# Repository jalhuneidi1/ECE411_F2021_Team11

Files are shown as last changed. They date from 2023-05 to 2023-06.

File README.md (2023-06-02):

# ECE411 Sunrise Alarm Clock - Team 7
> "Never wake-up in darkness..."

Project created for ECE 411 - Industry Design Processes

Team Members - Jana, Maddie, Ashlei, Julia

*__Note: The final product of this project utilized a completely different set of hardware. Updates forthcoming. The Sunrise Alarm Clock is an add on board for an arduino which allows users to interact with an OLED display clock using guestures (videos demonstration of final product can be found in the [Demo directory](https://github.com/jalhuneidi1/ECE411_F2021_Team7/tree/main/Demo). The board features 12 RGB SMD LEDs which are used to display time in a meaningful way, indicate confirmation of guesture input, and provide an illuminated alarm experience. A buzzer along with two analog buttons are included to facilitate traditional inputs and alarms if necessary.__*

View the [Product Design Specification](./Product%20Design%20Specification%20v1.pdf) for more information.

Look at the [Project Board](https://github.com/31415pi/ECE_411_Winter_2021_Team_7/projects/1).

Schematic located at [Hardware/Schematic](./Hardware/Schematic.pdf).

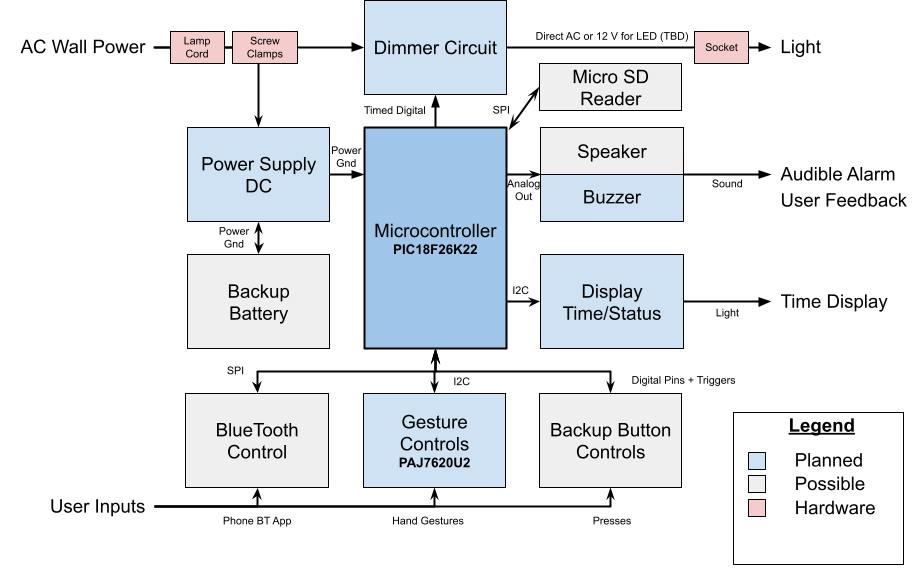
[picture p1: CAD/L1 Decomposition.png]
L1 Decomposition


## Parts List

Parts list on [google drive](https://docs.google.com/spreadsheets/d/1yFu2dnekZCLbKxV9tUKsMTaaS4XpjHtpUTBXEi358RU/edit#gid=0). [Convert to Markdown](https://tabletomarkdown.com/convert-spreadsheet-to-markdown/).

| Part (datasheet link) | Name | Type | Notes | Datasheet | Website | Source | Price  |
| --- | --- | --- | --- | --- | --- | --- | --- |
| [HT16K33](https://github.com/31415pi/ECE_411_Winter_2021_Team_7/blob/main/Datasheets/HT16K33v120(LEDcontroller).pdf) | RAM Mapping 16\*8 LED Controller Driver with keyscan | LED Controller  | | | [https://www.holtek.com/productdetail/-/vg/16K33](https://www.holtek.com/productdetail/-/vg/16K33) | | |
| [PIC18F26K42](https://github.com/31415pi/ECE_411_Winter_2021_Team_7/blob/main/Datasheets/PIC18(L)F26-27-45-46-47-55-56-57K42-Data-Sheet-40001919G.pdf) | | Microcontroller | Actual Model Read from Chip. | [https://www.microchip.com/content/dam/mchp/documents/MCU08/ProductDocuments/DataSheets/PIC18(L)F26-27-45-46-47-55-56-57K42-Data-Sheet-40001919G.pdf](https://www.microchip.com/content/dam/mchp/documents/MCU08/ProductDocuments/DataSheets/PIC18(L)F26-27-45-46-47-55-56-57K42-Data-Sheet-40001919G.pdf) | [https://www.microchip.com/en-us/product/PIC18F26K42](https://www.microchip.com/en-us/product/PIC18F26K42) | EPL | $ 1.50 |
| [IRM-05-5](https://github.com/31415pi/ECE_411_Winter_2021_Team_7/blob/main/Datasheets/IRM-05(ac-5vsupply).pdf) | | DC Power Supply | | | | [Mouser](https://www.mouser.com/ProductDetail/709-IRM05-5) | $ 8.81 |
| [MOC3052TVM](https://github.com/31415pi/ECE_411_Winter_2021_Team_7/blob/main/Datasheets/MOC3052M(ACcont).pdf) | | AC Controller | | | | [Mouser](https://www.mouser.com/ProductDetail/512-MOC3052SR2M)  | $ 1.15 |
| [ACST410-8BTR](https://github.com/31415pi/ECE_411_Winter_2021_Team_7/blob/main/Datasheets/ACST410(ACswitch).pdf) | | AC Switch | | | | [Mouser](https://www.mouser.com/ProductDetail/511-ACST410-8BTR) | $ 0.85 |
| [SFH628A](https://github.com/31415pi/ECE_411_Winter_2021_Team_7/blob/main/Datasheets/SFH628A(ACsensor).pdf) | | AC Sensor | | | | [Mouser](https://www.mouser.com/ProductDetail/782-SFH6286-4T) | $ 1.27 |
| [COM-10931](https://github.com/31415pi/ECE_411_Winter_2021_Team_7/blob/main/Datasheets/COM-10931_ATA3492BW(7seg4digitSparkfun).pdf) | 7-Segment Display - 4-Digit (White) | Time Display | | [http://cdn.sparkfun.com/datasheets/Components/LED/ATA3492BW\_2.pdf](http://cdn.sparkfun.com/datasheets/Components/LED/ATA3492BW_2.pdf) | [https://www.sparkfun.com/products/10931](https://www.sparkfun.com/products/10931) | [Mouser](https://www.mouser.com/ProductDetail/474-COM-10931) | $ 2.63 |

Alternate [Sparkfun Time Display](https://www.sparkfun.com/products/10931).

## Tools

- KiCad. [Third Party Libraries](https://www.kicad.org/libraries/third_party/)
- [Library Loader](https://componentsearchengine.com/tools) for loading schematics into KiCad and others. [Setup Instructions](https://www.samacsys.com/kicad/)

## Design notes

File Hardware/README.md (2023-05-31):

# Hardware Notes

Add libraries to KiCad. <https://www.samacsys.com/kicad/>

## Revisions

- v0.5 :
  - Updated 5v to 3.3v Power Supply.
  - Updated Logic control for LED Display.
    Use single decoder with V_IH = 1.5v. Works for 1-way control.
  - Added a third digit line for alarm and colon.
  - Finished buzzer circuit. Tested prototype.
  - Corrected Zero Crossing Circuit to be on power line always.
  - Corrected Triac Driver resistor to feedback from OUT of power triac.
  - Updated symbols.
  - AC System Done!
  - Added Jumper to Gesture Sensor.
  - Tested: Display Works fine with 3.3v. Use Either.
  - Added Oscillator
  - Added Varistor
- v0.4 :
	Schematic for LED Display.
	*Noticed LED Display needs 5v!*
	Add PIN assignments.
	Added PIN assignments for gesture sensor.
- v0.3 :
	Added Gesture Sensor.
	Switch to 3.3v supply. Modified resistors.
	Fix test_led. Added diode.
- v0.2 :
    Added LED time display.
	Added Buzzer.
	Added Test LED.
	Added Programing Header.
- v0.1 :
    Added PIC.
	Added AC circuit.
	Added Power supply. Use 5v supply lines.
	Added Rest button.

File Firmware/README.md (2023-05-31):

# Programing Setup

## Tools
[Microchip MPLAB](https://www.microchip.com/en-us/development-tools-tools-and-software/mplab-x-ide)
- Install 8-bit and 16-bit support.

[Code Configurator](https://www.microchip.com/en-us/development-tools-tools-and-software/embedded-software-center/mplab-code-configurator)

[XC Compilers](https://www.microchip.com/en-us/development-tools-tools-and-software/mplab-xc-compilers)

### MPLABX Guide / Tips

- `Ctrl-Click` on a symbol to go to definition.
- PICKit4 programmer has internal pull-downs of 4.7k on CLK, PDA lines.

To configure register access `Window -> Target Memory Views -> Configuration Bits`. This will allow to generate new configuration *pragmas*.

```
FEXTOSC - LP        : Use LP 32.768KHz low power mode.
RSTOSC  - LFINTOSC  : Use LP on reset.
MCLRE   -           : EXTMLCR
DEBUG   - ON        : Enable debugging.
WDTE    - Off       : Disable Watch Dog Timer for dev.
LVP     - OFF       : Must Use MCLR for programing in HV programing.
```

> The configuration is set for the target board to supply its own power but no voltage has been detected on VDD. Please ensure you have your target powered up and try again.
> Connection Failed.

`File > Project Properties` then in new window `Conf > PICkit 4`. Select `Option Categories: Power`. Here we can toggle external or internal. **Only 50mA of current provided at 5v.**

> Target Device ID (0x0) is an Invalid Device ID. Please check your connections to the Target Device.

You are probably not in debug mode.

> Warning: The hex file has the debug bit set.  The debug bit has been cleared during load to memory.  The original hex file has not been modified.

You are probably not in debug mode.

## Revisions

- v0.1
	- Basic Blink functionality
	- Prototype of AC controller on Arduino

## Device

[PIC18F26K22](../Datasheets/datasheet%20PIC18F26K22%20(microcontroller).pdf)
```
                                 ┌────┐__┌────┐
           PROG_EN  MCLR/VPP/RE3 ├  1      28 ┤ RB7/ICSP_DAT PGD
           ~SEG_A            RA0 ├  2      27 ┤ RB6/ICSP_CLK PGC
           ~SEG_B            RA1 ├  3      26 ┤ RB5                 *Speaker
           ~SEG_C            RA2 ├  4      25 ┤ RB4                ~BUZZER_EN
           ~SEG_D            RA3 ├  5      24 ┤ RB3                 TEST_LED
           ~SEG_E            RA4 ├  6      23 ┤ RB2      INT2 SDA2  *Extra Int
           ~SEG_F            RA5 ├  7      22 ┤ RB1      INT1 SCL2  GESTURE_INT
                             VSS ├  8      21 ┤ RB0      INT0       AC_ZEROX_INT
           ~SEG_G            RA7 ├  9      20 ┤ VDD
           ~SEG_DP           RA6 ├ 10      19 ┤ VSS
           DIGIT_A           RC0 ├ 11      18 ┤ RC7                 *Unused
           DIGIT_B           RC1 ├ 12      17 ┤ RC6      CTS1       TB2
           ~ALARM_EN         RC2 ├ 13      16 ┤ RC5      RX1        TB1
                  SCK1 SCL1  RC3 ├ 14      15 ┤ RC4      SDA1 SDI1
                                 ╘════════════╛
                                  PIC18F26K42
Stats:
64K Bytes Flash
32768 Single Word Instructions
3896 Bytes SRAM
1024 Bytes EEPROM
25   I/O
19   10-bit A/D Channels
2    SPI
2    I2C
3    8-bit timers
4    16-bit timers

19 Free Pins. 167seg. 1 buzzer. 1 ac control. 1 sound.

with SPI 17 free pins. 
```

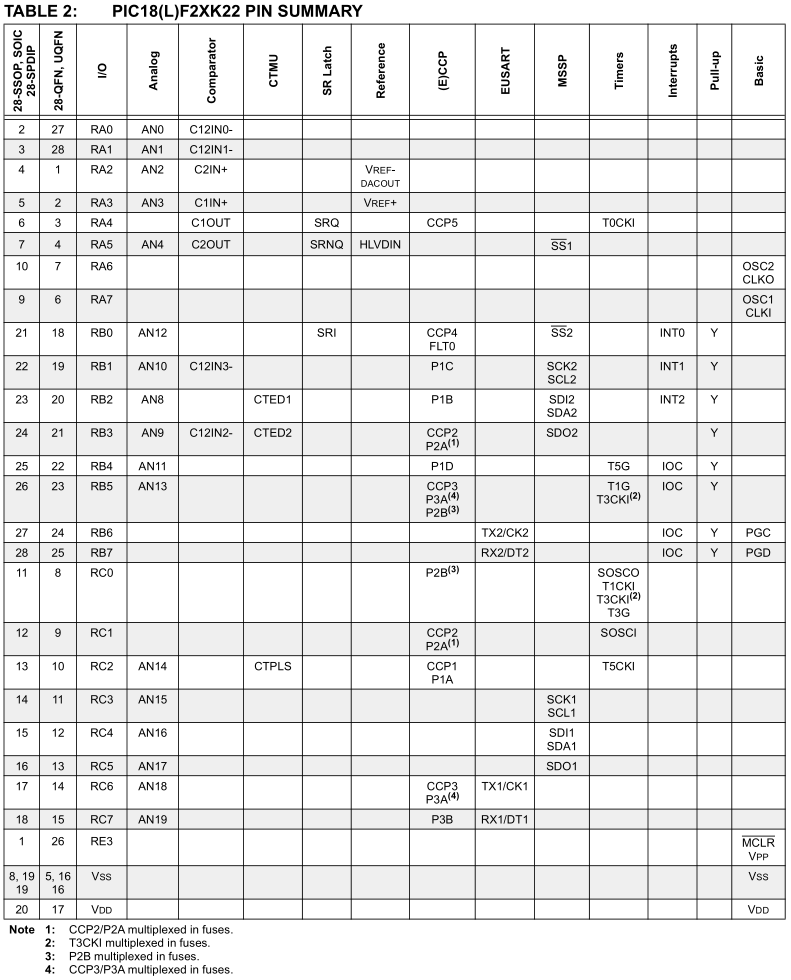
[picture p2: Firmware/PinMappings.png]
Additional Pin Mappings


## Reset
Reset is done via the MCLR pin. Active low for reset. Can be toggled by MCLRE pin.

## In-Circuit Programing ICPS
Mode is PGC and PGD.
LVP bit must be enabled.

24.9 Single-Supply ICSP Programming.
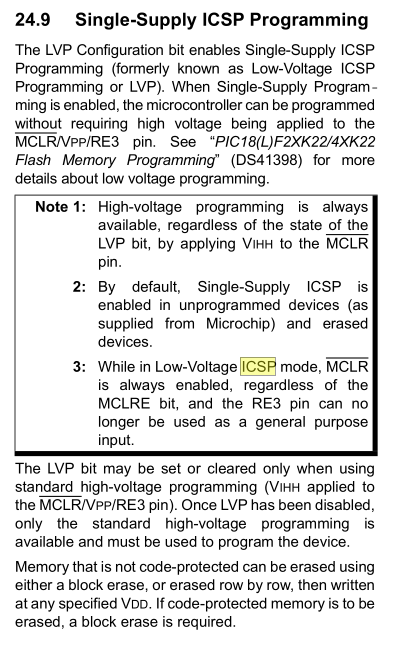
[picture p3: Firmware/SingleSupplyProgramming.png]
Single-Supply Programing


See "Flash Memory Programming".

> The LVP bit may be set or cleared only when using standard high-voltage
> programming (VIHH applied to the MCLR/VPP/RE3 pin). Once LVP has been
> disabled, only the standard high-voltage programming is available and must
> be used to program the device.

## Compare Modules
Ref 14.2 Compare Mode in datasheet.
Compare mode lets us trigger and external event a set-time after

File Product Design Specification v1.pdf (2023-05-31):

# Product Design Specification

## Sunrise Alarm Clock - Team 7 Version 1.0

Concept of Operations | 2
Market Analysis | 2
Table 1: Comparison to competition | 3
Requirements | 4
Must | 4
Should | 4
May | 4
System Architecture | 5
Figure 1: L1 Decomposition Block Diagram | 5
Design Specification | 5
Processor - Microcontroller | 5
Sensor - Gesture Control | 5
Power - AC to DC Supply | 5
Actuator - Triac to Light Bulb Socket / DC LED Strip | 5
Actuator - Buzzer/Speaker | 6
Actuator - Seven Segment Display | 6
References | 6

# Concept of Operations

The sunrise alarm clock wakes you up by gradually increasing the light in your room. Even in the darkness of Winter, waking up early should be a luminous experience that stimulates your natural circadian rhythm. Our device works to gently wake you up with a gradually brightening light and wake up sound. The light rises in brightness for 30 minutes before the alarm. While the alarm gets gradually louder to use the minimal volume needed to stir you from your slumber. The alarm clock will double as a bedside lamp to make a perfect addition to your home..

Night workers, anyone without an established early rise routine, and those hard of hearing will love using the bright light to knock you awake. While anyone with issues getting up in the morning will love the changes to your natural sleep rhythm. Plus a replaceable standard lightbulb to allow for selecting the perfect lightbulb maximum brightness and color temperature for your individual needs.

“Never start your day with darkness again.” - Team 7

# Market Analysis

While most have switched to using their phones for alarm clocks and many people use bedside lamps for reading and room lighting. McFarlane of the Royal Melbourne Institute of Technology surveyed people 18-60 and showed that 14% use physical alarm clocks [1 p9]. While 84% use phone alarms to wake-up, the market for physical alarms does still exist; by adding features and doubling as a bedside lamp we can penetrate the market. Further, the data in the study show that 92% wakeup to the same audio each day and preferred volume varies greatly [1 p9]. We can conclude that a large adjustable range of volume is needed for the wakeup sounds to meet user preferences. A gradual increase in volume would probably work best to keep all users happy. Below are some other conditions and users that we consider.

- People who are deaf.
- People who don’t want to disturb their partner.
- People who have trouble waking up in the morning (Philip’s studies confirm).
- Night workers and people who rise before the sun.
- Parents of teenagers.

Existing products don’t cover our listed requirements. Philips is the market leader in the tech offering two dimmable clock options. There are many options available by other manufacturers all copying the main features of the philips solution and adding some additional features such as temperature monitoring. Philips hase listed a clinical study of the effectiveness of their product. Confusingly Philips states their brightness in units of LUX which is area dependent. Alternatively a “Gesture & light alarm clock” app exists for Android and iOS that tries to offer the same features. Gesture controlled alarm clock (https://www.indiegogo.com/projects/oboo-the-1st-gesture-controlled-smart-alarm-clock) exists as an Indiegogo campaign but is no longer in production and lacks any dimming features. Philips HUE lights exist and can mimic this wakeup functionality via sync through your phone, but proprietary application and bluetooth protocol is required with little user options and customization and no direct clock features. One product (https://www.aliexpress.com/i/1005002755038746.html)

exists on AliExpress with gesture control and humidity/temperature display; this has no user replaceable bulb.

| Philips SmartSleep HF3520 (https://www.amazon.com/Philips-Simulation-Headspace-Subscription-HF3520/dp/B0093162RM) | Philips SmartSleep HF3650 (https://www.amazon.com/dp/B075S53HD9) | JALL Sunrise Alarm Clock (https://www.amazon.com/Sunrise-Sleepers-Simulation-Nightlight-Daylight/dp/B081CHLF46) | Ours
Cost | $99.99 | $179.95 | $45.98 | TBD
Features | FM radio, tap snooze and automatic dimmable display | midnight lamp, FM radio, phone charging dock, power back-up, speaker, auto dimming display and smart snooze | 2 alarms, FM Radio, 7 Sounds | Gesture Control Auto Dimming Display.
Sounds | 5 Sounds, Radio | 7 Sounds, Radio | 7 Sounds, Radio | User SD Card. Bring your own music, Possible play from phone.
Light, Brightness | 300 Lux, 20 steps, Non-replaceable | 310 Lux, 25 steps, Non-replaceable | 20 steps, Non-replaceable | AC Light bulb. User selectable/ Changeable. Like a lamp.
Power Backup | None | Full | None | Alarm Only

Table 1: Comparison to competition

## Requirements

### Must

- Must have easily user-replaceable light.
- Must have wall socket AC power power.
- Must attempt to wake the user on time.
- Must have control of brightness.
- Must turn off alarm by user interaction
- Must display time
- Must have user set alarm
- Must have basic clock/alarm interactions: Set time. Set Alarm. Cancel Alarm.
- Must have basic lamp features: On, Off, Dimming.

### Should

- Should be intuitive enough to learn controls in 10 minutes.
- Should have backup power (Only for alarm, display)
- Should have physical interaction backup buttons(In case of sensor failure)
- Should keep accurate time within ±5 minutes lost per year
- Should adjust display brightness to light conditions.
- Should have options for light only alarms.
- Should be quiet during operation with suggested lights.
- Should

### May

- May support custom audio for wakeup.
- May be configurable via Bluetooth ®
- May have USB power output to charge the phone.
- May have USB data input to connect to the phone for music.
- May have clap on/off sensor.
- May speak with users to guide settings.
- May have night light feature.

## System Architecture

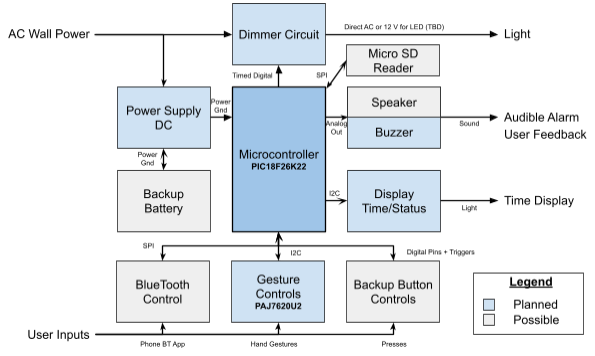
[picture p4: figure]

Figure 1: L1 Decomposition Block Diagram

## Design Specification

### Processor - Microcontroller

PIC18F26K22 (https://www.microchip.com/en-us/product/PIC18F26K22) can be used as the main controller. It has many pins for the various connections we need and is available in the EPL to start prototyping quickly.

### Sensor - Gesture Control

PAJ7620U2 sensor with 9 gestures. Left, Right, Up, Down, Forward, Back, Clockwise, Counterclock wise, and wave. Connect to this by I2C. This is the main control input unit.

### Power - AC to DC Supply

Use prefab AC to 5V Power Supply. Check for safety features. Option is HI-LINK HKL-5M05 for 5V power. May be able to use lower voltage.

### Actuator - Triac to Light Bulb Socket / DC LED Strip

Used for modulating AC voltage based on microcontroller input. Connects to dimmable LED. We will additionally explore using a DC LED strip to produce the desired brightness.

### Actuator - Buzzer/Speaker

Used to create the alarm sound. Controlled with a direct output from the microcontroller.

### Actuator - Seven Segment Display

Used to display time and some configuration settings. Should be dimmable to avoid bright light in darkness. May need a separate controller depending on complexity. https://www.sparkfun.com/products/11441

## References

[1] McFarlane SJ, Garcia JE, Verhagen DS, Dyer AG (2020) Alarm tones, music and their elements: Analysis of reported waking sounds to counteract sleep inertia. PLOS ONE 15(1): e0215788. https://doi.org/10.1371/journal.pone.0215788

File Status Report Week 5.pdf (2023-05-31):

# Status Report Week 5

### Sunrise Alarm Clock - Team 7

## Oct 27th 2021

Parts are either ordered or in hand.

- Gesture sensors on route
- Analog parts on route est Oct 29th
- Displays arrived or enroute
- PIC have but need to distribute to teammates. (Today)
- Buzzers selected

Prototype is still minimal. Have read that we can use an Arduino to program, still figuring it out. Have a backup programmer on the way.

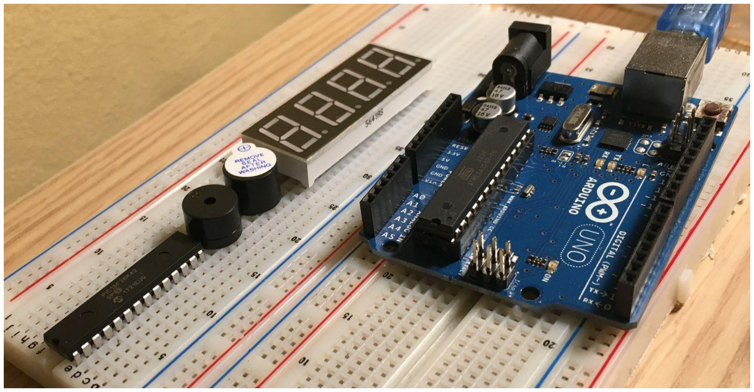
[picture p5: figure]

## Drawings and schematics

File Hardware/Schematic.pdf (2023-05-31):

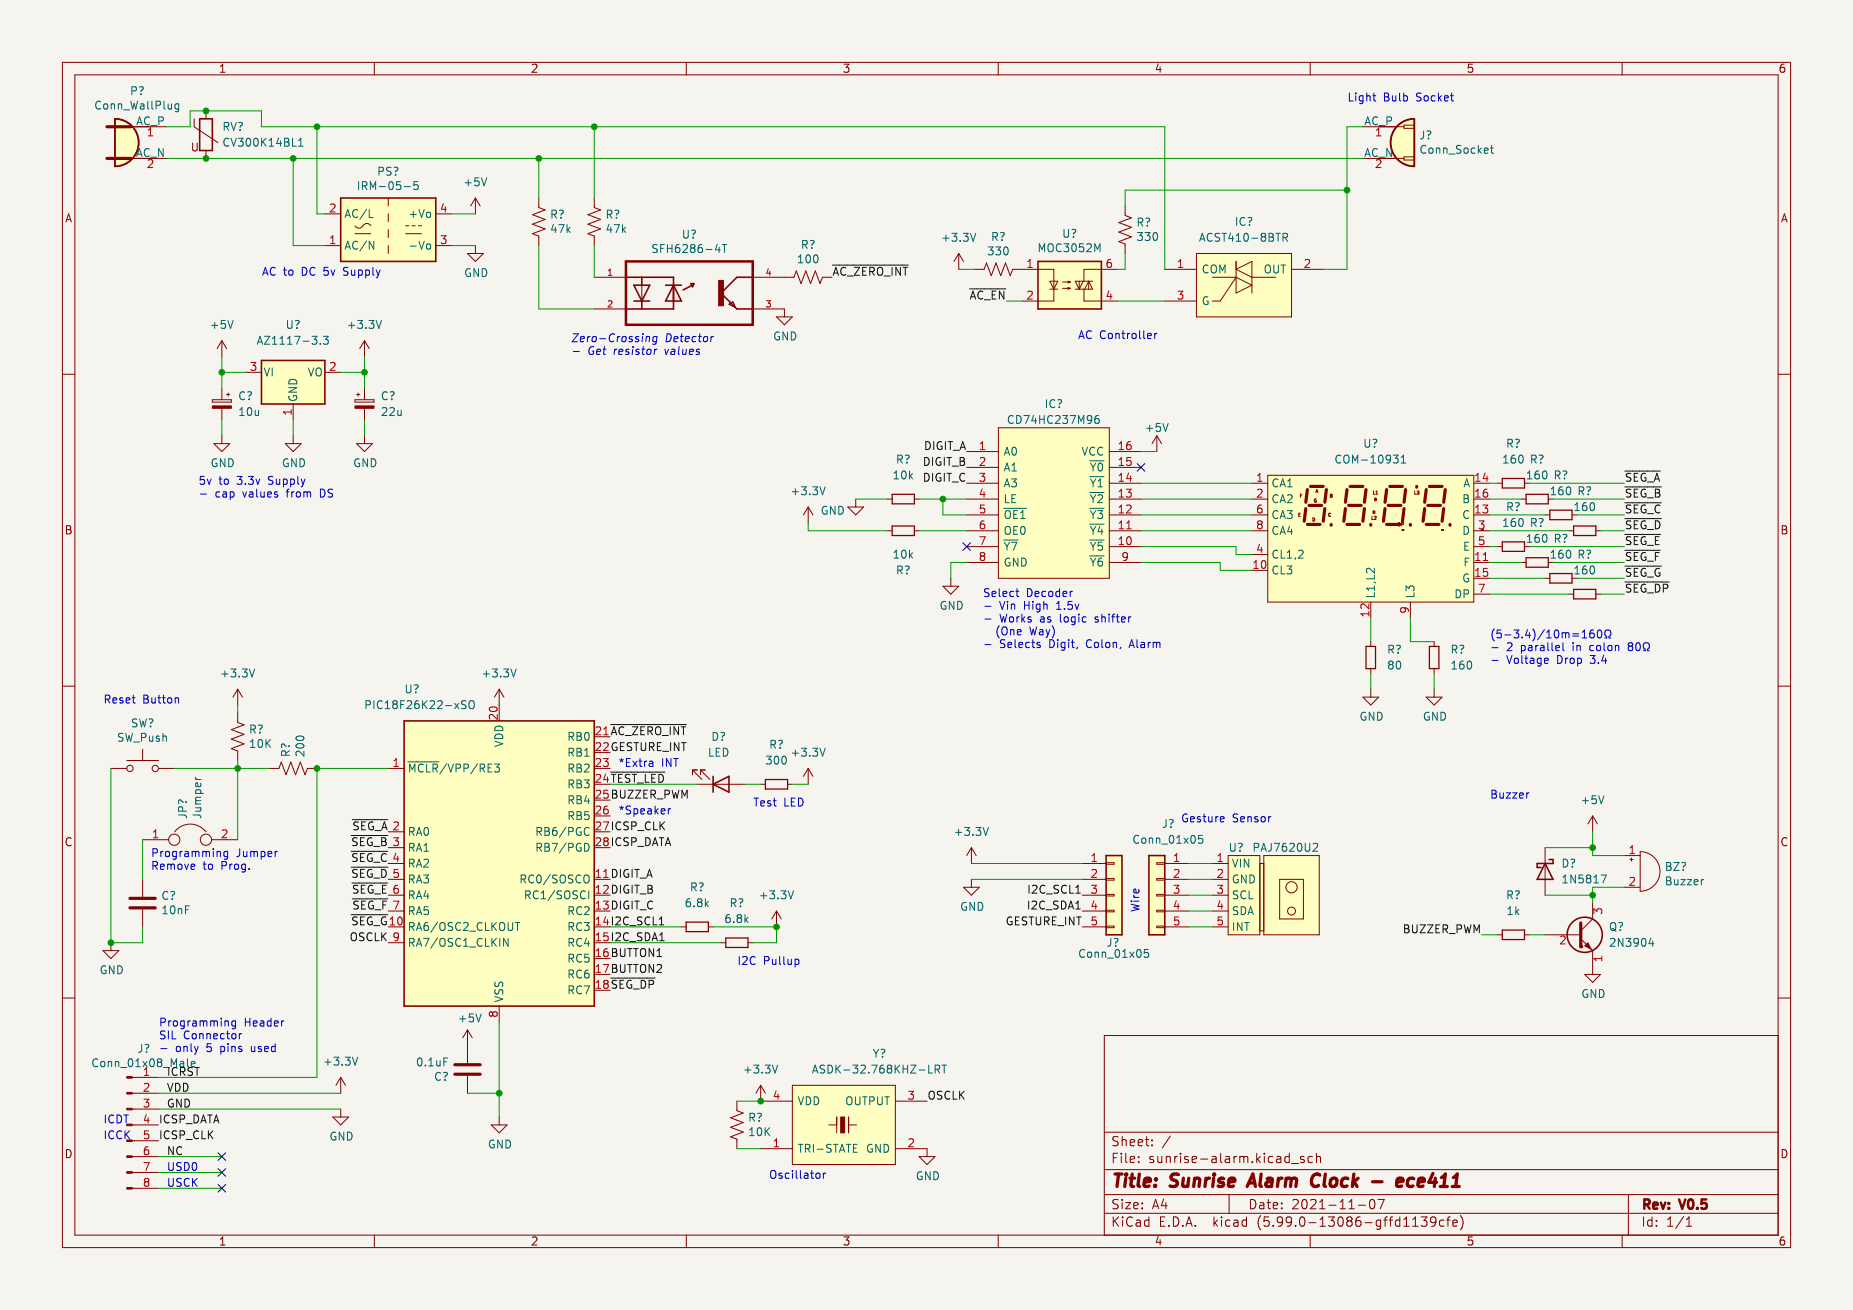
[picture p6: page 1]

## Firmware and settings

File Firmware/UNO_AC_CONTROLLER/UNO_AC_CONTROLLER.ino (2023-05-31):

// Interrupts on digital pins 2,3
const int pin_zerox_int = 2;
const int pin_ac_en = 4;
const int apin_pot = A0;

const long half_period_us = (int) (1000000.f / 60 / 2); // ~8.3ms / 8333us

bool ac_enable = false;
long  ac_enable_delay_us = half_period_us; // 0 full power
long  ac_enable_percent = 0;
long  ac_enable_raw = 0;

void on_zerox_int() {
  Serial.println("interrupt zerox");
  
  digitalWrite(pin_ac_en, LOW);

  if (ac_enable && ac_enable_delay_us < half_period_us) {
    delayMicroseconds(ac_enable_delay_us);
    digitalWrite(pin_ac_en, HIGH);
  }
}

#define ANALOG_MAX 1023l
void update_ac(long percent_power) {
  ac_enable_raw = constrain(percent_power, 0, ANALOG_MAX);
  ac_enable_percent = (100 * ac_enable_raw) / ANALOG_MAX;
  ac_enable_delay_us = ((ANALOG_MAX - ac_enable_raw) * half_period_us) / ANALOG_MAX;

  Serial.print(ac_enable ? "AC: ENABLED   " : "AC: disabled  ");
  Serial.print(ac_enable_percent);
  Serial.print("%   ");
  Serial.print(ac_enable_raw);
  Serial.print("    ");
  Serial.print(ac_enable_delay_us);
  Serial.println(" us");
}

void setup() {
  // put your setup code here, to run once:
  pinMode(apin_pot, INPUT);
  pinMode(pin_ac_en, OUTPUT);
  pinMode(pin_zerox_int, INPUT_PULLUP);
  // MODE: LOW, CHANGE, RISING, FALLING 
  attachInterrupt(digitalPinToInterrupt(pin_zerox_int), on_zerox_int, FALLING);
  
  Serial.begin(38400);
  delay(50); // Allow for serial to load.
  Serial.println("Start");
}

int pot_value = 0;
void loop() {
  long val = analogRead(apin_pot);
  if (val != pot_value) {
    pot_value = val;
    update_ac(pot_value);
  }
  
  delay(100);
}

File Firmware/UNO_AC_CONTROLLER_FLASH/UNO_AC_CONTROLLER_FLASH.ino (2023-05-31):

// Interrupts on digital pins 2,3
const int pin_zerox_int = 2;
const int pin_ac_en = 4;
const int apin_pot = A0;


const long half_period_us = (int) (1000000.f / (60 * 2)); // ~8.3ms / 8333us

typedef unsigned long ulong;

bool  ac_enable = true;
long  ac_enable_delay_us = half_period_us; // 0 full power
long  ac_enable_percent = 0;
long  ac_enable_raw = 0;
ulong ac_xings = 0;
ulong ac_xings_prev = 0;

void on_zerox_int() {
  ++ac_xings;
  //Serial.println("interrupt zerox"); // Don't Print.
  
  digitalWrite(pin_ac_en, LOW);

  if (ac_enable && ac_enable_delay_us < half_period_us - 200) {
    //noInterrupts();
    
    delayMicroseconds(ac_enable_delay_us); // TODO: Timer
    digitalWrite(pin_ac_en, HIGH);
    // TODO: Turn off even if no zeroxings occur after delay. Stays on 50%.
    
    //interrupts();
  }
}


#define ANALOG_MAX 1023l
void ac_update(long percent_power) {
  ac_enable_raw = constrain(percent_power, 0, ANALOG_MAX);
  ac_enable_percent = (100 * ac_enable_raw) / ANALOG_MAX;
  ac_enable_delay_us = ((ANALOG_MAX - ac_enable_raw) * half_period_us) / ANALOG_MAX;

  Serial.print(ac_enable ? "AC: ENABLED   " : "AC: disabled  ");
  Serial.print(ac_enable_percent);
  Serial.print("%   ");
  Serial.print(ac_enable_raw);
  Serial.print("    ");
  Serial.print(ac_enable_delay_us);
  Serial.println(" us");
}

void ac_measure() {
  ulong xings;
  ulong diff;
  ulong elapsed;
  ulong dt;
  static ulong t = 0;

  elapsed = millis();

  // TODO: Compute crossing rate.
  dt = elapsed - t;
  if (dt > 1000) { // Once per second.
    t += dt;

    xings = ac_xings;
    diff  = xings - ac_xings_prev;
    ac_xings_prev = xings;
  
    Serial.print(diff);
   Serial.println(" crossings");
  }
  
  
}

void setup() {
  Serial.begin(38400);
  delay(50); // Allow for serial to load.
  Serial.println("Start");
  
  // put your setup code here, to run once:
  pinMode(apin_pot, INPUT);
  pinMode(pin_ac_en, OUTPUT);
  pinMode(pin_zerox_int, INPUT_PULLUP);
  // MODE: LOW, CHANGE, RISING, FALLING 
  attachInterrupt(digitalPinToInterrupt(pin_zerox_int), on_zerox_int, FALLING);
}

int pot_value = 0;
void loop() {
  long val;
  
  val = analogRead(apin_pot);
  if (val != pot_value) {
    pot_value = val;
    ac_update(pot_value);
  }

  delay(25);
  ac_measure();
  
}
